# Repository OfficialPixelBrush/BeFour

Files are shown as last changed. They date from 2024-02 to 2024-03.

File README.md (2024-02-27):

# BeFour
The BeFour/B4/Be4 is a simplistic 4-Bit, TTL Processor, largely inspired by the Zilog Z80 and similar architectures of the late-1970s and early-1980s, just in 4-Bit.

# Goal
It's main idea is simple. How basic can I make an instruction set, while still making it somewhat useful?
This question arose out of need. I was originally trying to make a Diode-Transistor Logic Computer entirely from Scratch, which was meant to be 4-Bit too. However, planning that monstrocity became too difficult for my current skill-set, so I decided to try anew. My main goal not being an impressive instruction set, but something simple that won't require heaps of individual Diodes and Transistors. This is also why I'll be sticking with bog-standard TTL Chips for this project.

# Architecture
This Processor is entirely 4-Bit, aside from the Address Bus, which is 8-Bit.
This allows for Addressing of up to 256 Bytes of Memory, at least as a Program. The Processor is only capable of reading a 4-Bit address for RAM access, limiting it's Memory on that front to only 16 Bytes.

For more information about the Architecture, Instruction Set, Memory Map, et cetera, please [visit the Wiki page](https://github.com/OfficialPixelBrush/BeFour/wiki).

# Emulator
The provide Emulator is accurate enough for most simple Programs, and can be compiled easily with gcc.
Pre-built Binaries can usually be found in the Releases section, although these may not always be up-to-date.

## How to use
The emulator takes two parameters. The first is the filename of whichever Binary file it's supposed to execute. The second is how many instructions it'll execute before stopping. By default, this is -1, meaning it'll stop right away.

### Windows
To execute the provided Fibonacci Program, for example, one could use `.\b4emu.exe ..\software\fibo.bin 50` to execute the Fibbonaci Program for 50 Instructions.

### Linux
Similar to Windows, just different formatting:
`./b4emu ../software/fibo.bin 50`
Outside of that, make sure the binary is set to be executable.
`chmod +x b4emu`

## Binaries
You can find all Releases in the [Releases Section](https://github.com/OfficialPixelBrush/BeFour/releases).

# License
It's been difficult finding a proper license for this thus far, especially because I don't see why anyone'd want to do much with this thing.
It's my processor, feel free to be inspired by it, but don't steal it, and don't use it commercially. I'll probably replace this with a proper license sometime soon, but if you have any deeper questions, just shoot me a message via an Issue or something.

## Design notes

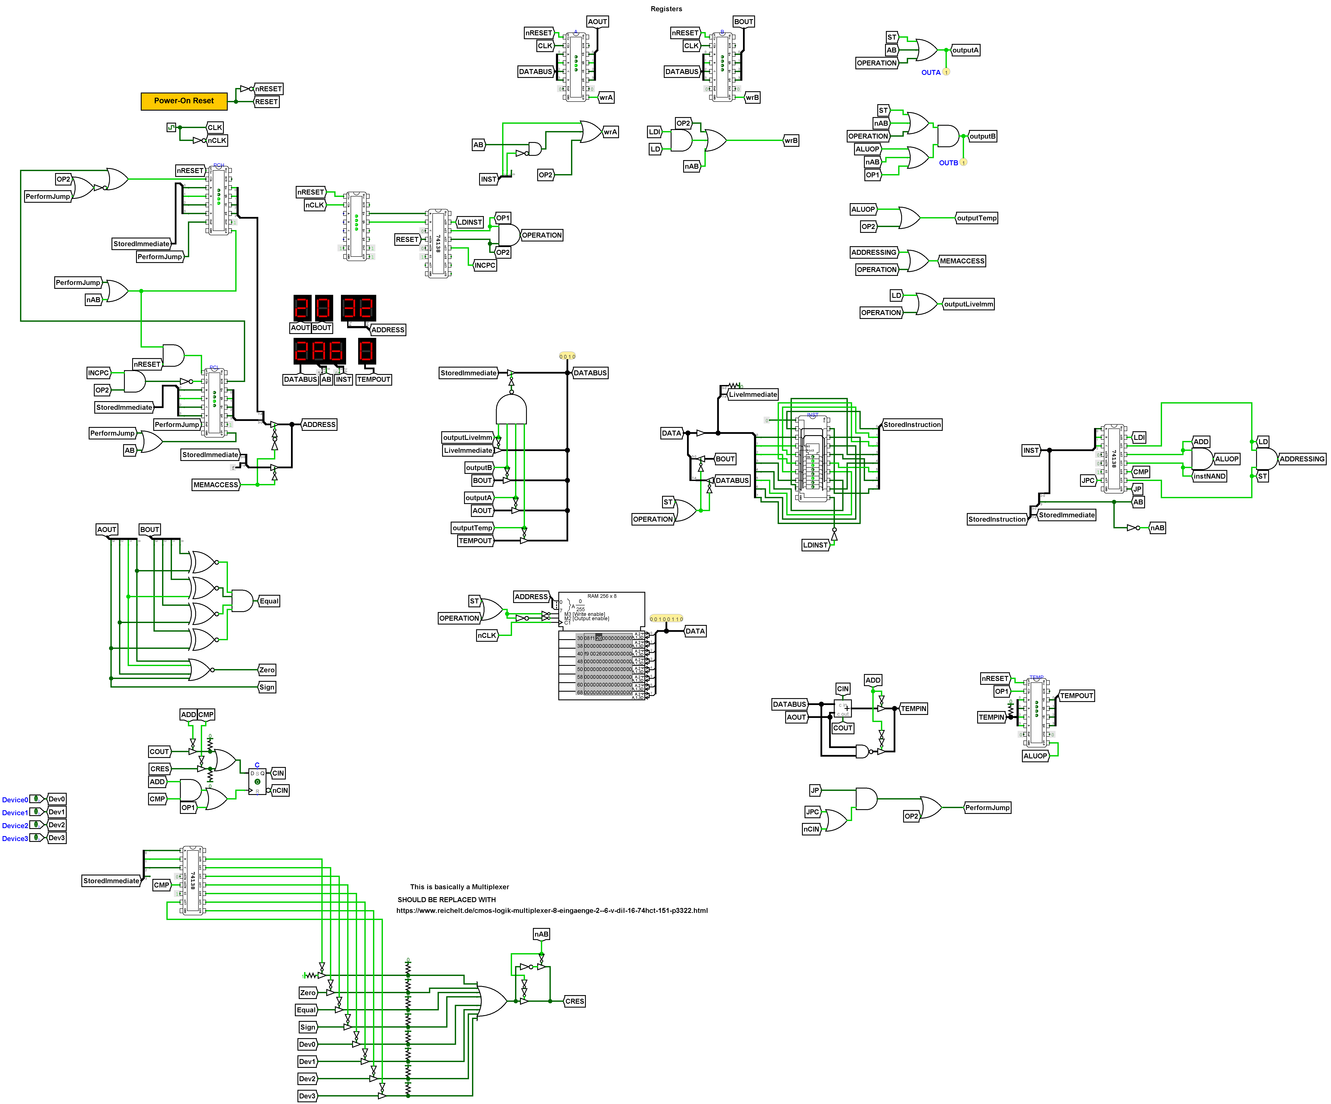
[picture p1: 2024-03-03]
images/befour_final.png

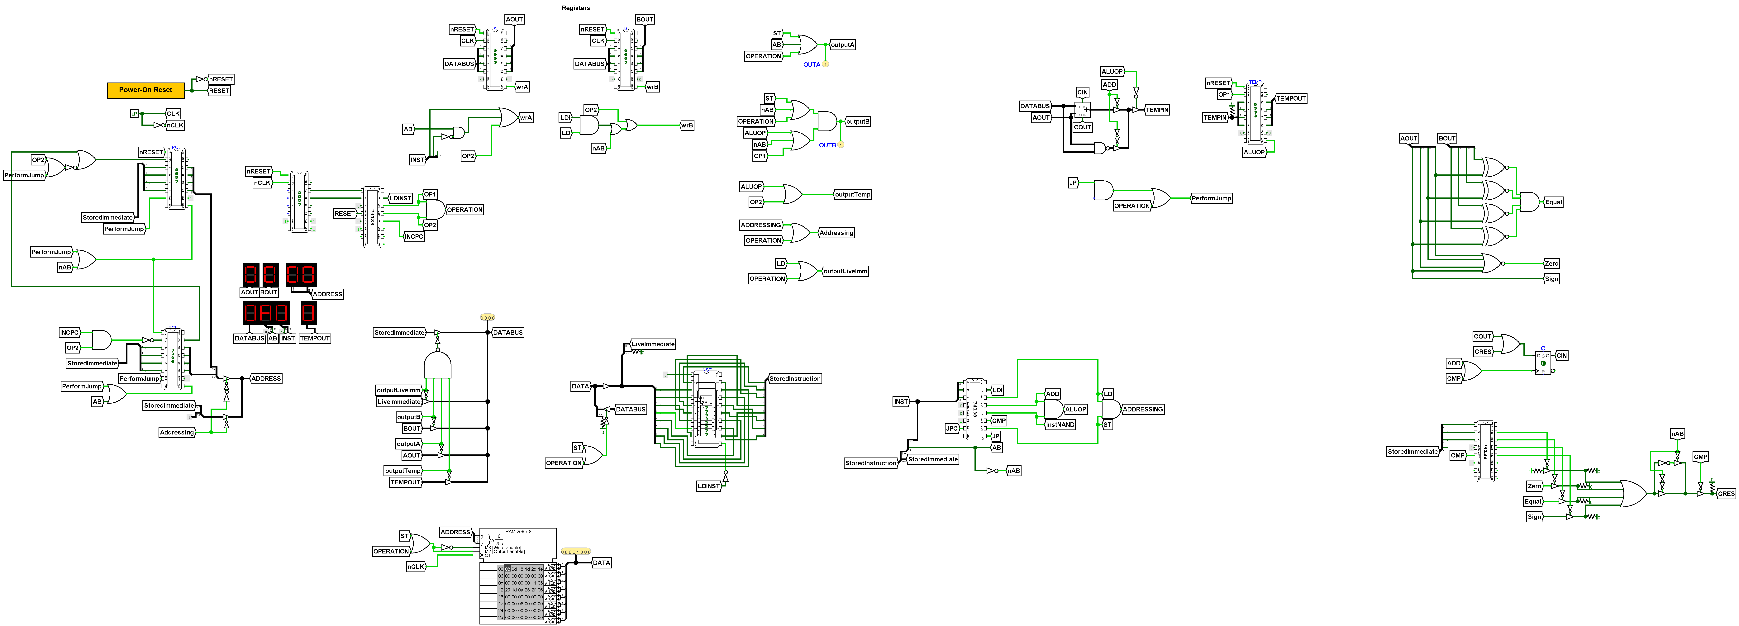
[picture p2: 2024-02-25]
images/basic4bit_cmp.png

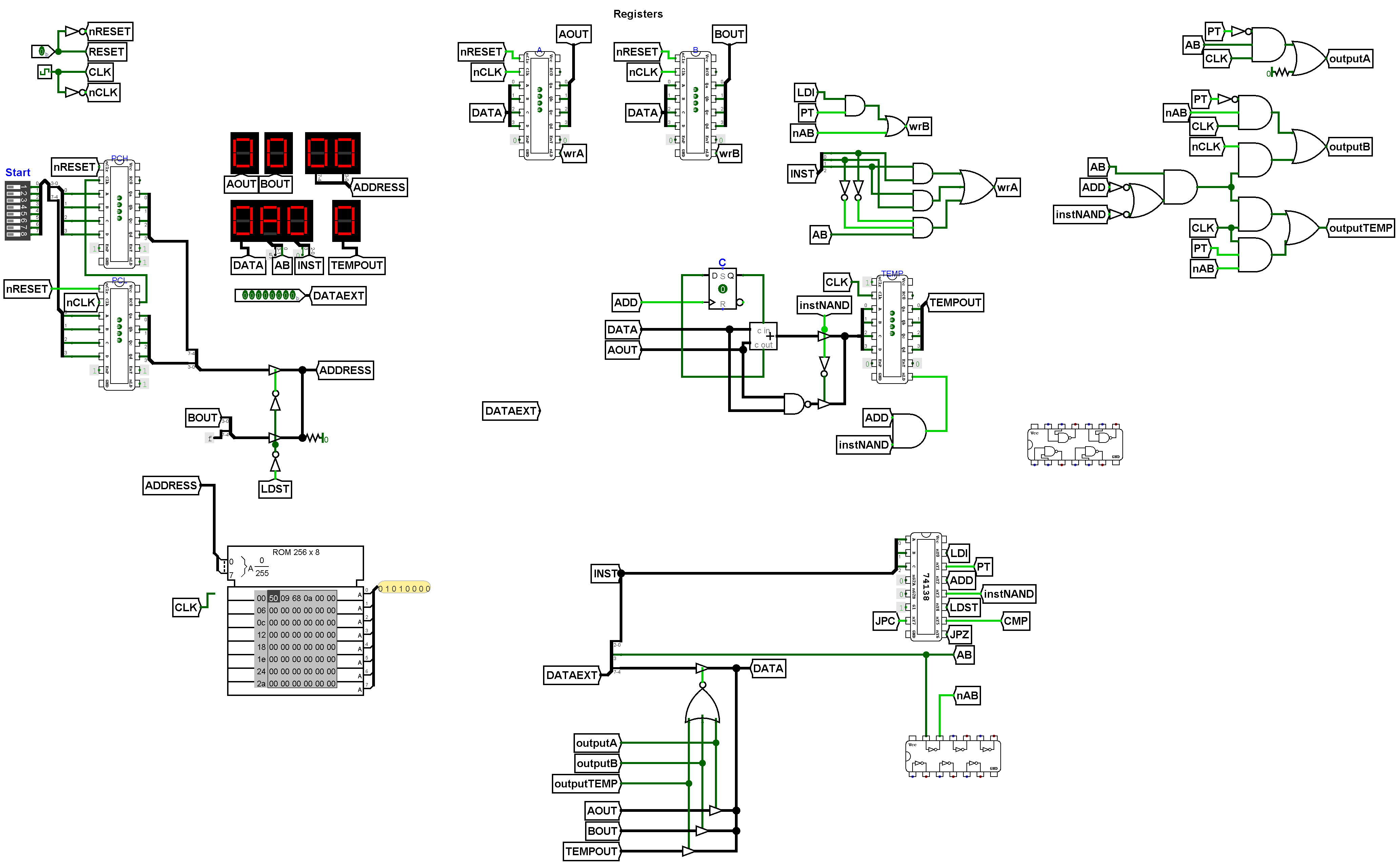
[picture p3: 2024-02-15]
images/basic4bit_halfway.png

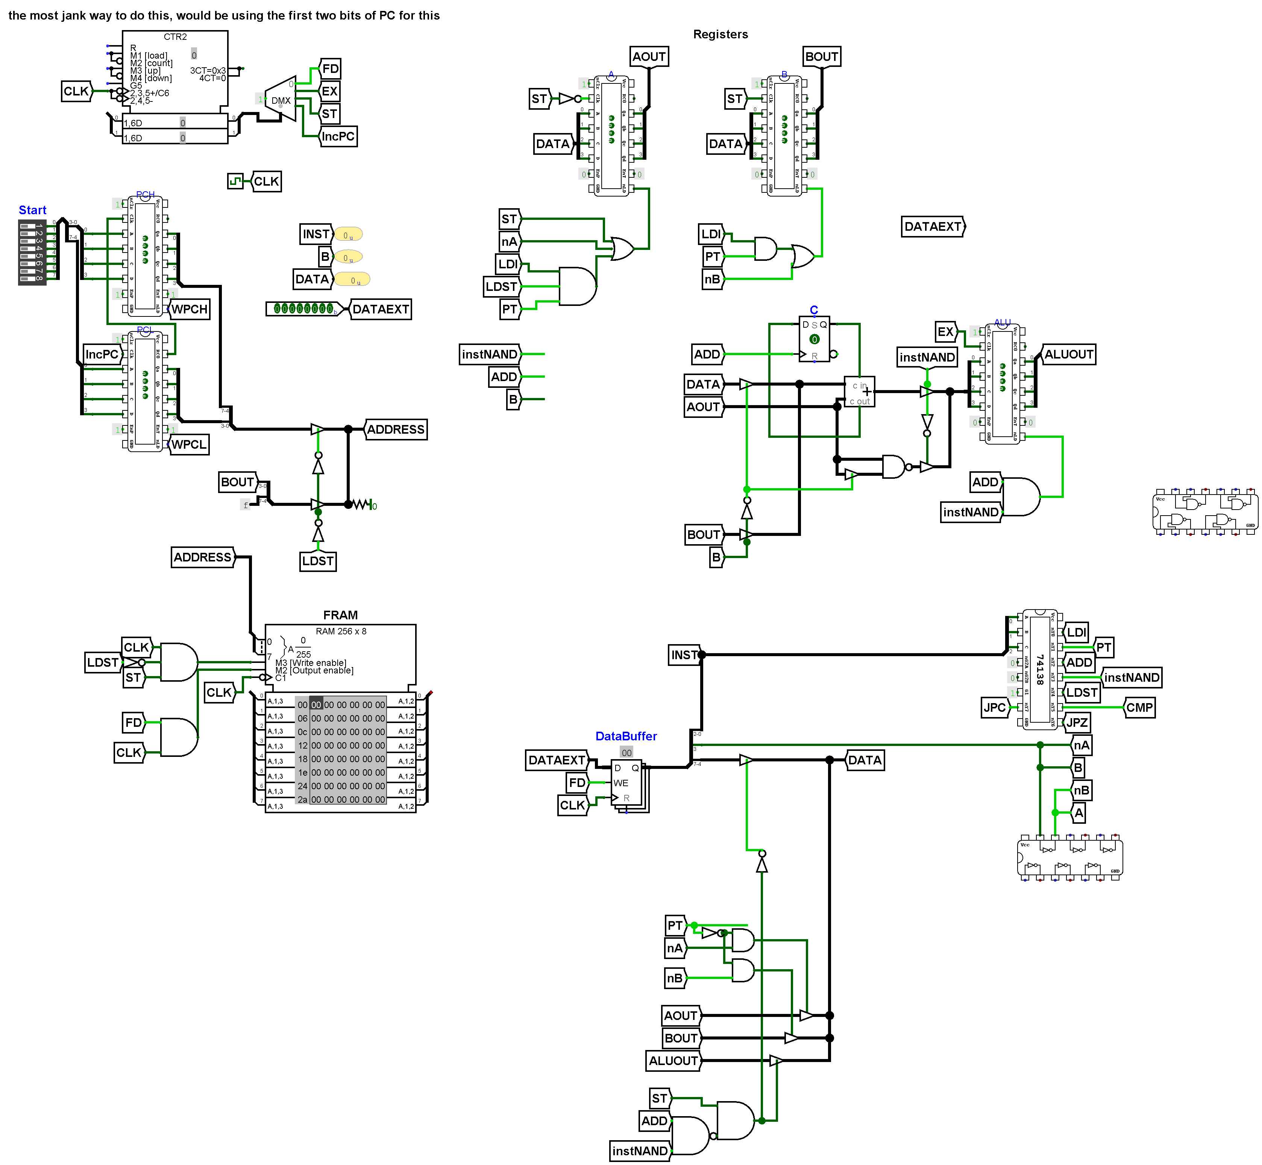
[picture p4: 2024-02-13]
images/basic4bit.png

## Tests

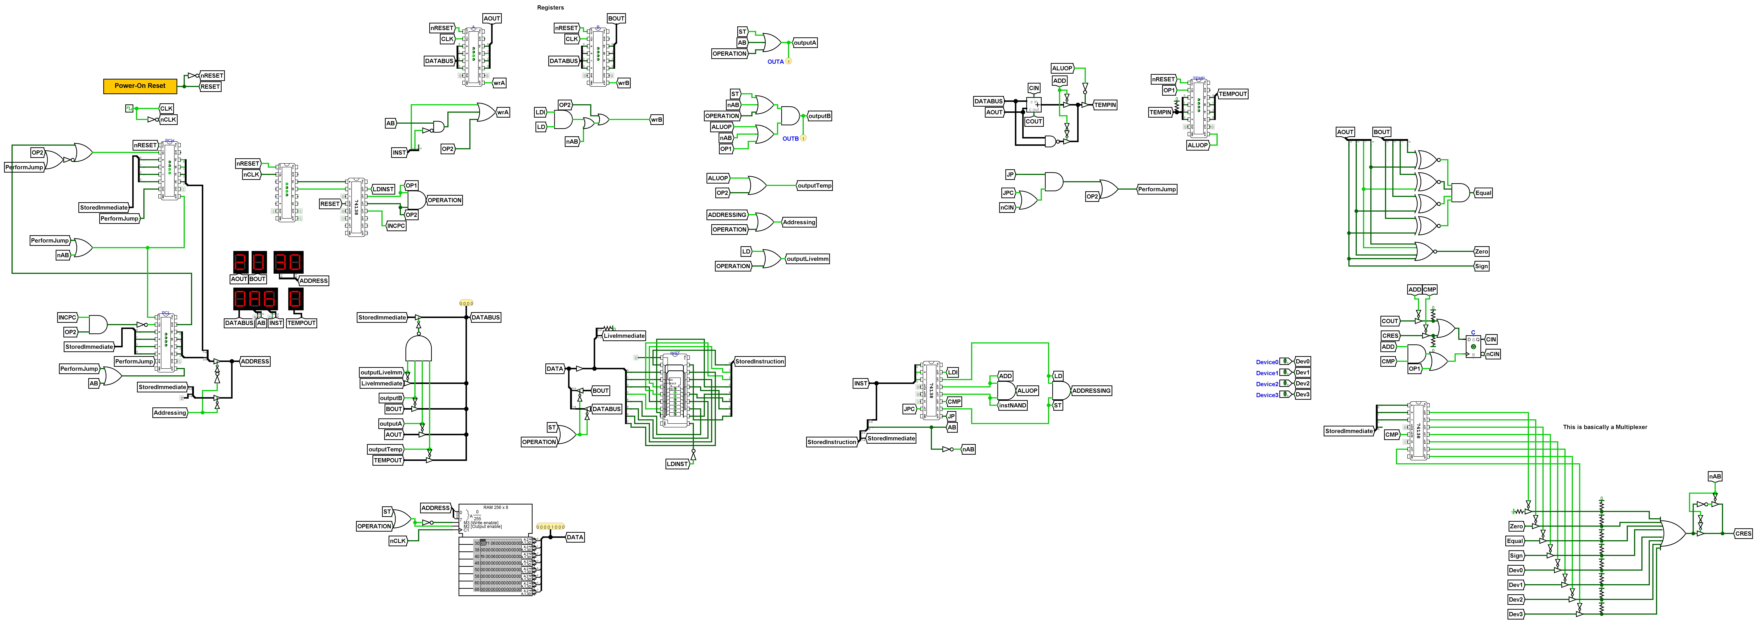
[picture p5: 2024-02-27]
images/befour_finishedTest.png

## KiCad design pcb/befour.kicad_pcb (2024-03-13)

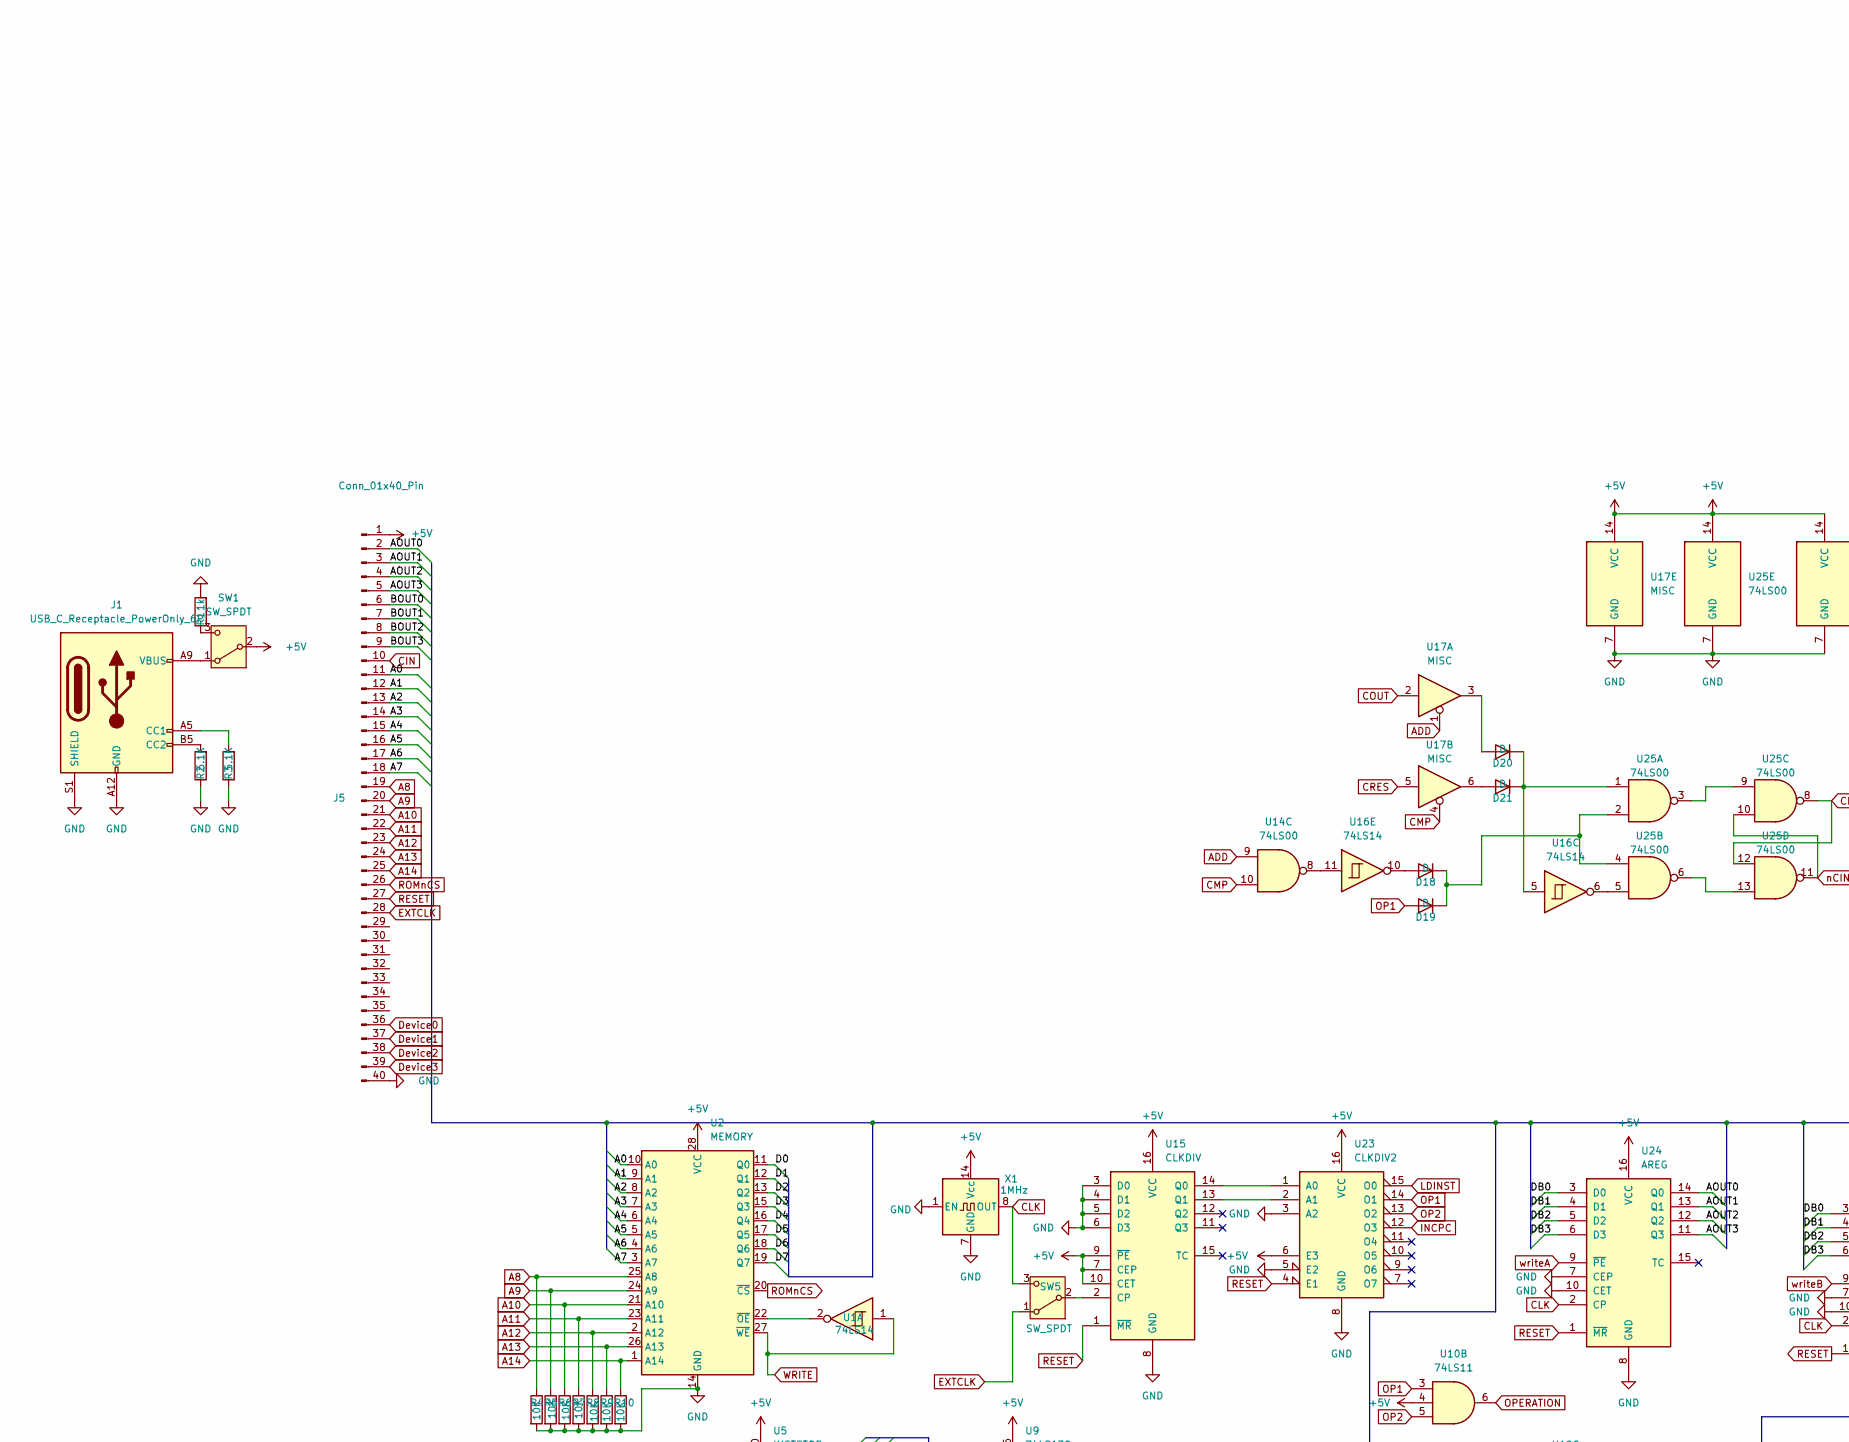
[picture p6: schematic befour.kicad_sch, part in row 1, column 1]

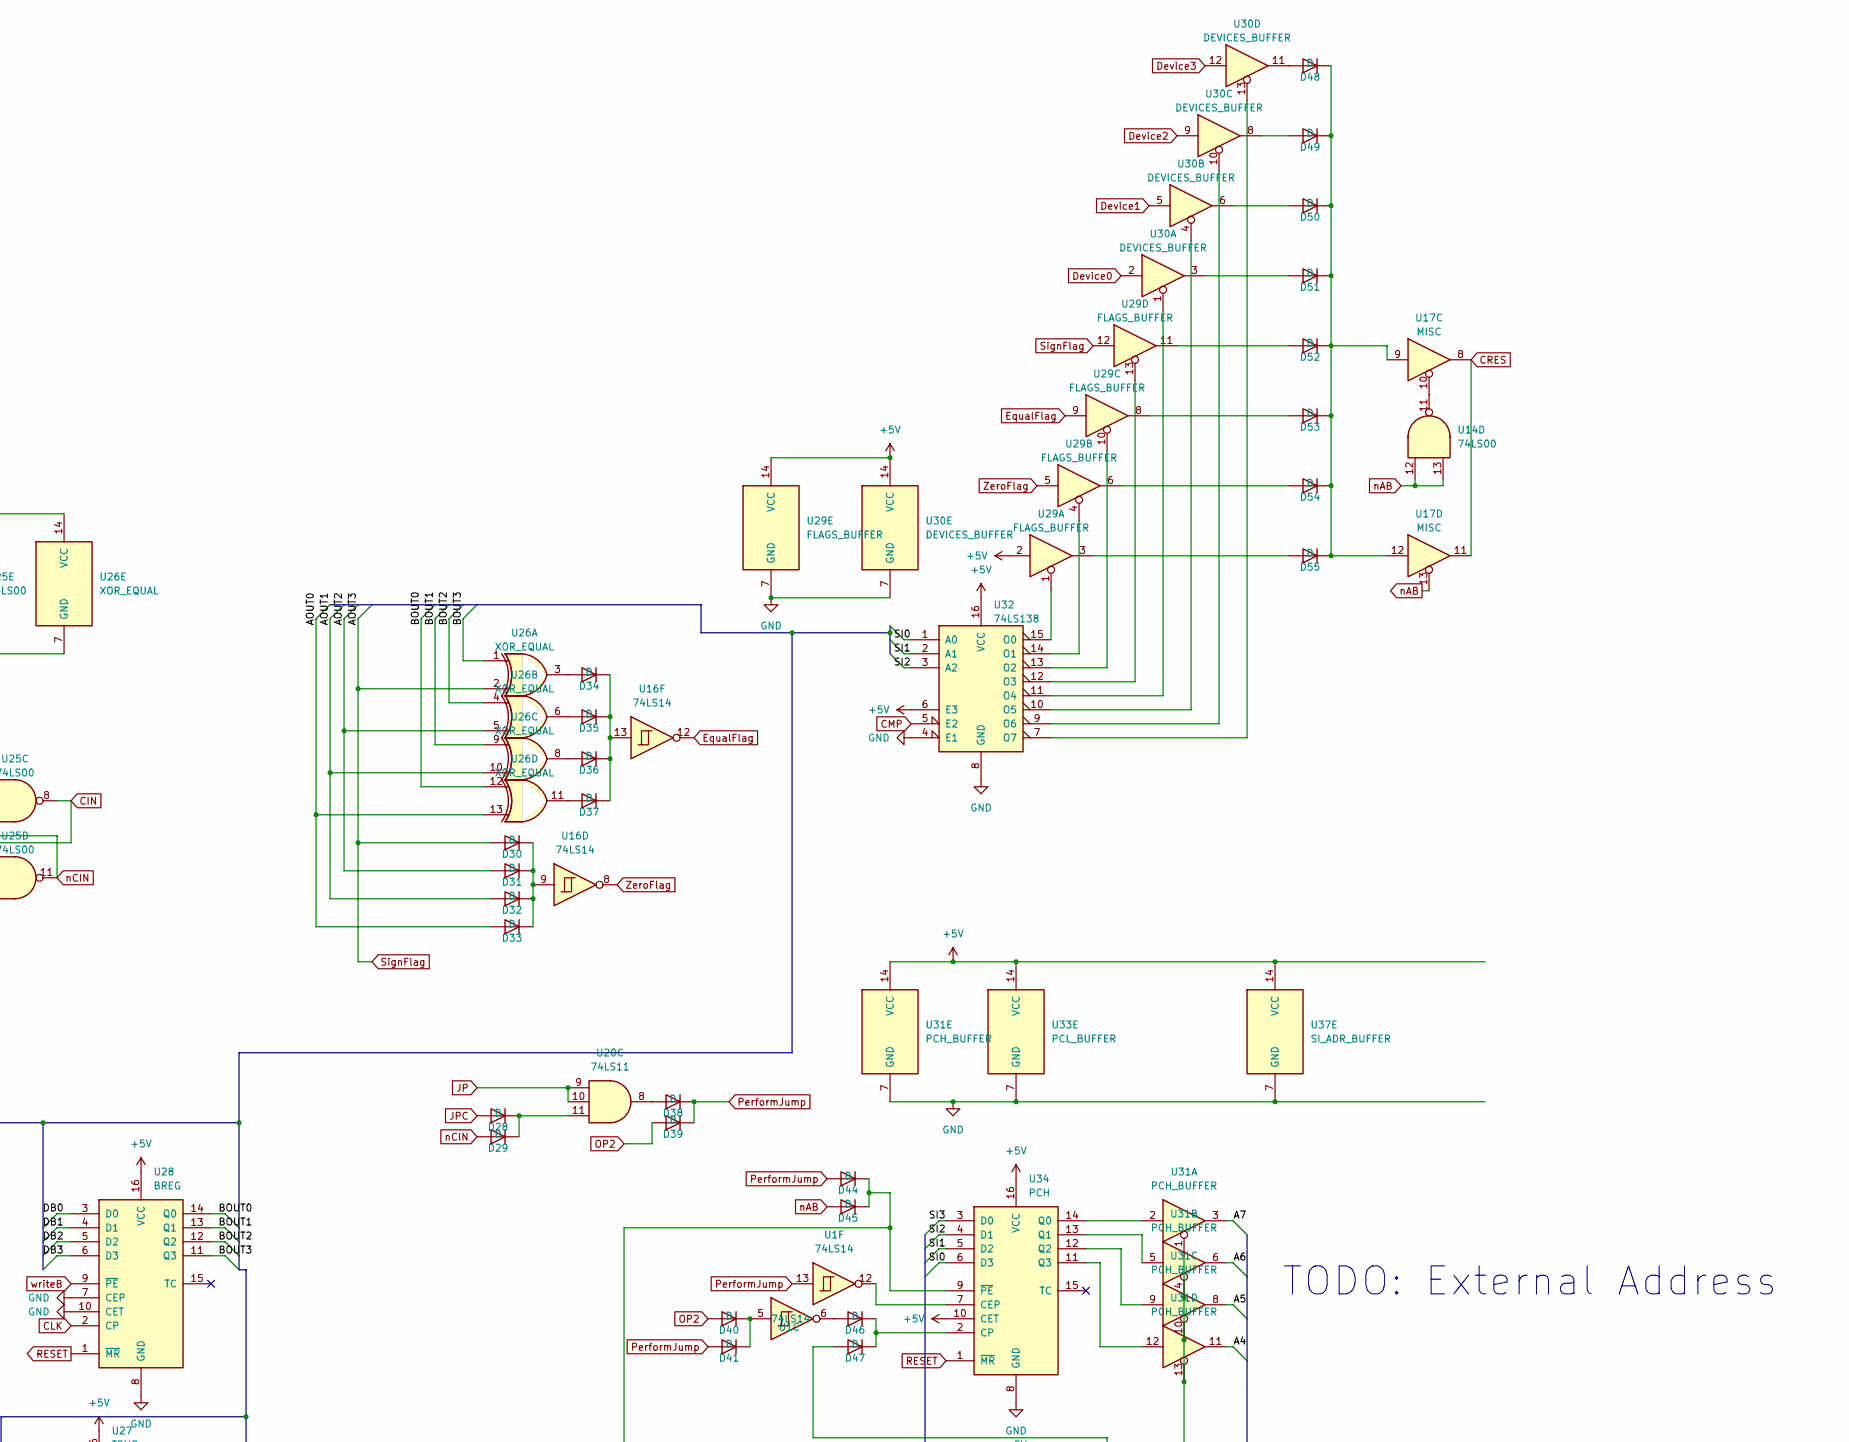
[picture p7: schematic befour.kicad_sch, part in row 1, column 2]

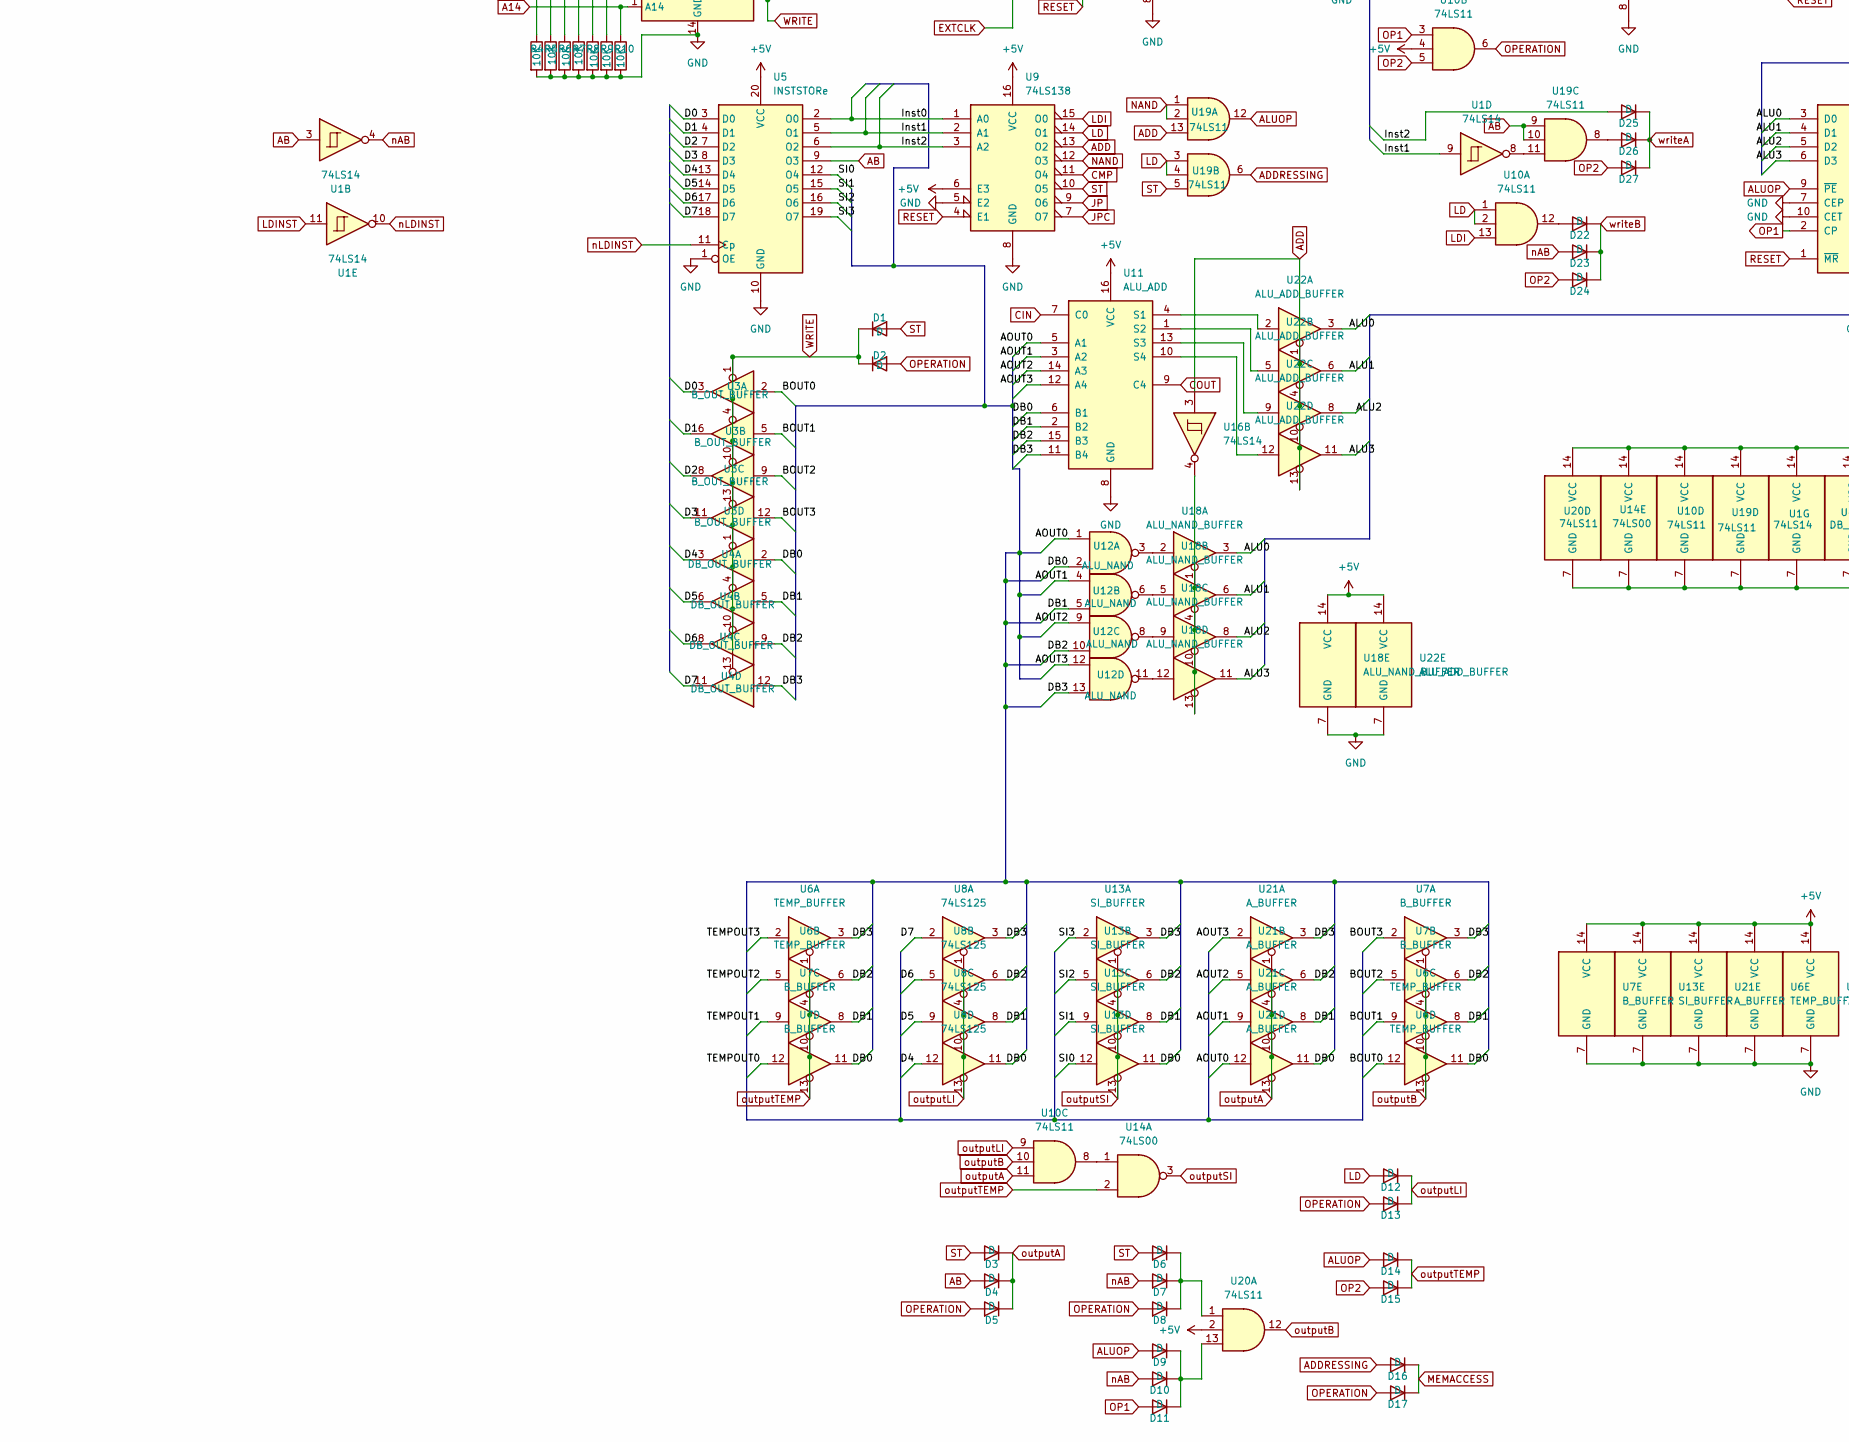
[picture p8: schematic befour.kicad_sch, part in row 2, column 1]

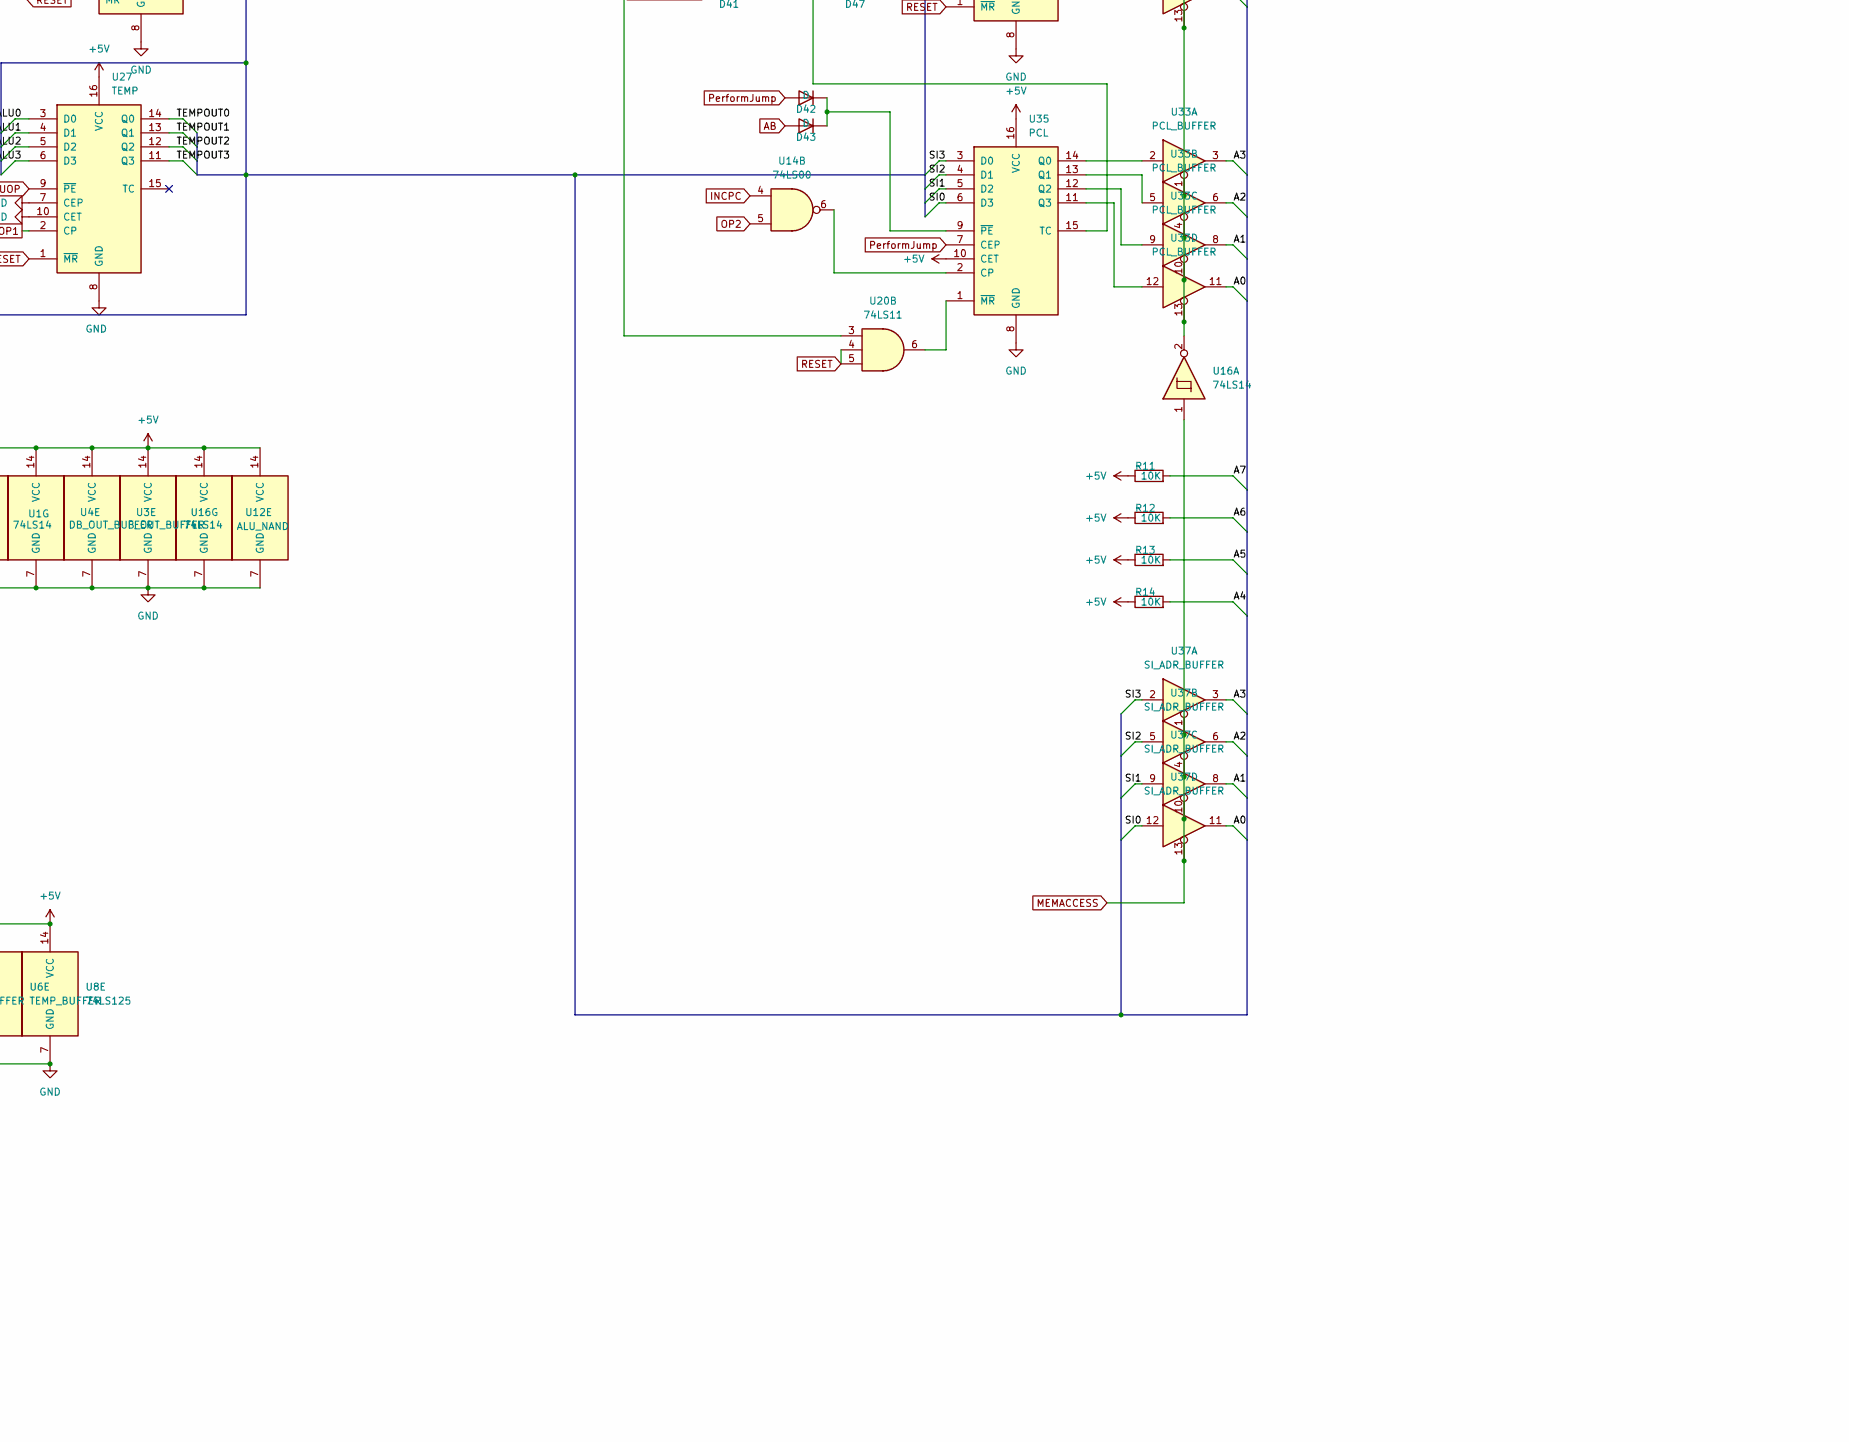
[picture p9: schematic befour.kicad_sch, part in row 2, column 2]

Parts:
D1, D2, D3, D4, D5, D6, D7, D8, D9, D10, D11, D12, D13, D14, D15, D16, D17, D18, D19, D20, D21, D22, D23, D24, D25, D26, D27, D28, D29, D30, D31, D32, D33, D34, D35, D36, D37, D38, D39, D40, D41, D42, D43, D44, D45, D46, D47, D48, D49, D50, D51, D52, D53, D54, D55: D; D_DO-35_SOD27_P2.54mm_Vertical_KathodeUp
J1: USB_C_Receptacle_PowerOnly_6P; USB_C_Receptacle_GCT_USB4125-xx-x_6P_TopMnt_Horizontal
J5: Conn_01x40_Pin; PinHeader_1x40_P2.54mm_Horizontal
R1: 1k; R_Axial_DIN0309_L9.0mm_D3.2mm_P2.54mm_Vertical
R2, R3: 5.1K; R_Axial_DIN0309_L9.0mm_D3.2mm_P2.54mm_Vertical
R4, R5, R6, R7, R8, R9, R10, R11, R12, R13, R14: 10K; R_Axial_DIN0309_L9.0mm_D3.2mm_P2.54mm_Vertical
SW1: SW_SPDT; PinHeader_1x03_P2.54mm_Vertical
SW5: SW_SPDT; SW_Slide_SPDT_Straight_CK_OS102011MS2Q
U1, U16: 74LS14; DIP-14_W7.62mm_Socket
U2: MEMORY; DIP-28_W15.24mm
U3: B_OUT_BUFFER; DIP-14_W7.62mm_Socket
U4: DB_OUT_BUFFER; DIP-14_W7.62mm_Socket
U5: INSTSTORe; DIP-20_W7.62mm_Socket
U6: TEMP_BUFFER; DIP-14_W7.62mm_Socket
U7: B_BUFFER; DIP-14_W7.62mm_Socket
U8: 74LS125; DIP-14_W7.62mm_Socket
U9, U32: 74LS138; DIP-16_W7.62mm_Socket
U10, U19, U20: 74LS11; DIP-14_W7.62mm_Socket
U11: ALU_ADD; DIP-16_W7.62mm_Socket
U12: ALU_NAND; DIP-14_W7.62mm_Socket
U13: SI_BUFFER; DIP-14_W7.62mm_Socket
U14, U25: 74LS00; DIP-14_W7.62mm_Socket
U15: CLKDIV; DIP-16_W7.62mm_Socket
U17: MISC; DIP-14_W7.62mm_Socket
U18: ALU_NAND_BUFFER; DIP-14_W7.62mm_Socket
U21: A_BUFFER; DIP-14_W7.62mm_Socket
U22: ALU_ADD_BUFFER; DIP-14_W7.62mm_Socket
U23: CLKDIV2; DIP-16_W7.62mm_Socket
U24: AREG; DIP-16_W7.62mm_Socket
U26: XOR_EQUAL; DIP-14_W7.62mm_Socket
U27: TEMP; DIP-16_W7.62mm_Socket
U28: BREG; DIP-16_W7.62mm_Socket
U29: FLAGS_BUFFER; DIP-14_W7.62mm_Socket
U30: DEVICES_BUFFER; DIP-14_W7.62mm_Socket
U31: PCH_BUFFER; DIP-14_W7.62mm_Socket
U33: PCL_BUFFER; DIP-14_W7.62mm_Socket
U34: PCH; DIP-16_W7.62mm_Socket
U35: PCL; DIP-16_W7.62mm_Socket
U37: SI_ADR_BUFFER; DIP-14_W7.62mm_Socket
X1: 1MHz; Oscillator_DIP-14

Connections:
+5V: J5.1, R11.1, R12.1, R13.1, R14.1, SW1.2 (B), U1.14 (VCC), U2.28 (VCC), U3.14 (VCC), U4.14 (VCC), U5.20 (VCC), U6.14 (VCC), U7.14 (VCC), U8.14 (VCC), U9.6 (E3), U9.16 (VCC), U10.4, U10.14 (VCC), U11.16 (VCC), U12.14 (VCC), U13.14 (VCC), U14.14 (VCC), U15.7 (CEP), U15.9 (~PE), U15.10 (CET), U15.16 (VCC), U16.14 (VCC), U17.14 (VCC), U18.14 (VCC), U19.14 (VCC), U20.2, U20.14 (VCC), U21.14 (VCC), U22.14 (VCC), U23.6 (E3), U23.16 (VCC), U24.16 (VCC), U25.14 (VCC), U26.14 (VCC), U27.16 (VCC), U28.16 (VCC), U29.2, U29.14 (VCC), U30.14 (VCC), U31.14 (VCC), U32.6 (E3), U32.16 (VCC), U33.14 (VCC), U34.10 (CET), U34.16 (VCC), U35.10 (CET), U35.16 (VCC), U37.14 (VCC), X1.14 (Vcc)
/A0: J5.11, U2.10 (A0), U33.11, U37.11
/A1: J5.12, U2.9 (A1), U33.8, U37.8
/A2: J5.13, U2.8 (A2), U33.6, U37.6
/A3: J5.14, U2.7 (A3), U33.3, U37.3
/A4: J5.15, R14.2, U2.6 (A4), U31.11
/A5: J5.16, R13.2, U2.5 (A5), U31.8
/A6: J5.17, R12.2, U2.4 (A6), U31.6
/A7: J5.18, R11.2, U2.3 (A7), U31.3
/ALU0: U18.3, U22.3, U27.3 (D0)
/ALU1: U18.6, U22.6, U27.4 (D1)
/ALU2: U18.8, U22.8, U27.5 (D2)
/ALU3: U18.11, U22.11, U27.6 (D3)
/AOUT0: D33.2 (A), J5.2, U11.5 (A1), U12.1, U21.12, U24.14 (Q0), U26.13
/AOUT1: D32.2 (A), J5.3, U11.3 (A2), U12.4, U21.9, U24.13 (Q1), U26.10
/AOUT2: D31.2 (A), J5.4, U11.14 (A3), U12.9, U21.5, U24.12 (Q2), U26.5
/BOUT0: J5.6, U3.2, U6.12, U26.12, U28.14 (Q0)
/BOUT1: J5.7, U3.5, U6.9, U26.9, U28.13 (Q1)
/BOUT2: J5.8, U3.9, U7.5, U26.4, U28.12 (Q2)
/BOUT3: J5.9, U3.12, U7.2, U26.1, U28.11 (Q3)
/D0: U2.11 (Q0), U3.3, U5.3 (D0)
/D1: U2.12 (Q1), U3.6, U5.4 (D1)
/D2: U2.13 (Q2), U3.8, U5.7 (D2)
/D3: U2.15 (Q3), U3.11, U5.8 (D3)
/D4: U2.16 (Q4), U4.3, U5.13 (D4), U8.12
/D5: U2.17 (Q5), U4.6, U5.14 (D5), U8.9
/D6: U2.18 (Q6), U4.8, U5.17 (D6), U8.5
/D7: U2.19 (Q7), U4.11, U5.18 (D7), U8.2
/DB0: U4.2, U6.11, U7.11, U8.11, U11.6 (B1), U12.2, U13.11, U21.11, U24.3 (D0), U28.3 (D0)
/DB1: U4.5, U6.8, U7.8, U8.8, U11.2 (B2), U12.5, U13.8, U21.8, U24.4 (D1), U28.4 (D1)
/DB2: U4.9, U6.6, U7.6, U8.6, U11.15 (B3), U12.10, U13.6, U21.6, U24.5 (D2), U28.5 (D2)
/DB3: U4.12, U6.3, U7.3, U8.3, U11.11 (B4), U12.13, U13.3, U21.3, U24.6 (D3), U28.6 (D3)
/Inst0: U5.2 (O0), U9.1 (A0)
/Inst1: U1.9, U5.5 (O1), U9.2 (A1)
/Inst2: D25.2 (A), U5.6 (O2), U9.3 (A2)
/SI0: U5.12 (O4), U13.12, U32.1 (A0), U34.6 (D3), U35.6 (D3), U37.12
/SI1: U5.15 (O5), U13.9, U32.2 (A1), U34.5 (D2), U35.5 (D2), U37.9
/SI2: U5.16 (O6), U13.5, U32.3 (A2), U34.4 (D1), U35.4 (D1), U37.5
/SI3: U5.19 (O7), U13.2, U34.3 (D0), U35.3 (D0), U37.2
/TEMPOUT0: U7.12, U27.14 (Q0)
/TEMPOUT1: U7.9, U27.13 (Q1)
/TEMPOUT2: U6.5, U27.12 (Q2)
/TEMPOUT3: U6.2, U27.11 (Q3)
A8: J5.19, R4.1, U2.25 (A8)
A9: J5.20, R5.1, U2.24 (A9)
A10: J5.21, R6.1, U2.21 (A10)
A11: J5.22, R7.1, U2.23 (A11)
A12: J5.23, R8.1, U2.2 (A12)
A13: J5.24, R9.1, U2.26 (A13)
A14: J5.25, R10.1, U2.1 (A14)
AB: D4.2 (A), D43.2 (A), U1.3, U5.9 (O3), U19.9, U19.10
ADD: U9.13 (O2), U14.9, U16.3, U17.1, U19.13, U22.1, U22.4, U22.10, U22.13
ADDRESSING: D16.2 (A), U19.6
ALUOP: D9.2 (A), D14.2 (A), U19.12, U27.9 (~PE)
CIN: J5.10, U11.7 (C0), U25.8, U25.12
CLK: SW5.3 (C), U24.2 (CP), U28.2 (CP), X1.8 (OUT)
CMP: U9.11 (O4), U14.10, U17.4, U32.5 (E2)
COUT: U11.9 (C4), U17.2
CRES: U17.5, U17.8, U17.11
Device0: J5.36, U30.2
Device1: J5.37, U30.5
Device2: J5.38, U30.9
Device3: J5.39, U30.12
EXTCLK: J5.28, SW5.1 (A)
EqualFlag: U16.12, U29.9
GND: J1.A12 (GND), J1.B12 (GND), J1.S1 (SHIELD), J5.40, R1.2, R2.1, R3.1, R4.2, R5.2, R6.2, R7.2, R8.2, R9.2, R10.2, U1.7 (GND), U2.14 (GND), U3.7 (GND), U4.7 (GND), U5.1 (OE), U5.10 (GND), U6.7 (GND), U7.7 (GND), U8.7 (GND), U9.5 (E2), U9.8 (GND), U10.7 (GND), U11.8 (GND), U12.7 (GND), U13.7 (GND), U14.7 (GND), U15.3 (D0), U15.4 (D1), U15.5 (D2), U15.6 (D3), U15.8 (GND), U16.7 (GND), U17.7 (GND), U18.7 (GND), U19.7 (GND), U20.7 (GND), U21.7 (GND), U22.7 (GND), U23.3 (A2), U23.5 (E2), U23.8 (GND), U24.7 (CEP), U24.8 (GND), U24.10 (CET), U25.7 (GND), U26.7 (GND), U27.7 (CEP), U27.8 (GND), U27.10 (CET), U28.7 (CEP), U28.8 (GND), U28.10 (CET), U29.7 (GND), U30.7 (GND), U31.7 (GND), U32.4 (E1), U32.8 (GND), U33.7 (GND), U34.8 (GND), U35.8 (GND), U37.7 (GND), X1.1 (EN), X1.7 (GND)
INCPC: U14.4, U23.12 (O3)
JP: U9.9 (O6), U20.9, U20.10
JPC: D28.2 (A), U9.7 (O7)
LD: D12.2 (A), U9.14 (O1), U10.1, U10.2, U19.3, U19.4
LDI: U9.15 (O0), U10.13
LDINST: U1.11, U23.15 (O0)
MEMACCESS: D16.1 (K), D17.1 (K), U16.1, U37.1, U37.4, U37.10, U37.13
NAND: U9.12 (O3), U19.1, U19.2
unnamed: D6.1 (K), D7.1 (K), D8.1 (K), U20.1
unnamed: D9.1 (K), D10.1 (K), D11.1 (K), U20.13
unnamed: D18.2 (A), U16.10
unnamed: D18.1 (K), D19.1 (K), U25.2, U25.4
unnamed: D20.2 (A), U17.3
unnamed: D20.1 (K), D21.1 (K), U16.5, U25.1
unnamed: D21.2 (A), U17.6
unnamed: D22.2 (A), U10.12
unnamed: D26.2 (A), U19.8
unnamed: D28.1 (K), D29.1 (K), U20.11
unnamed: D30.1 (K), D31.1 (K), D32.1 (K), D33.1 (K), U16.9
unnamed: D34.2 (A), U26.3
unnamed: D34.1 (K), D35.1 (K), D36.1 (K), D37.1 (K), U16.13
unnamed: D35.2 (A), U26.6
unnamed: D36.2 (A), U26.8
unnamed: D37.2 (A), U26.11
unnamed: D38.2 (A), U20.8
unnamed: D40.1 (K), D41.1 (K), U1.5
unnamed: D42.1 (K), D43.1 (K), U35.9 (~PE)
unnamed: D44.1 (K), D45.1 (K), U20.3, U34.9 (~PE)
unnamed: D46.2 (A), U1.6
unnamed: D46.1 (K), D47.1 (K), U34.2 (CP)
unnamed: D47.2 (A), U35.15 (TC)
unnamed: D48.2 (A), U30.11
unnamed: D48.1 (K), D49.1 (K), D50.1 (K), D51.1 (K), D52.1 (K), D53.1 (K), D54.1 (K), D55.1 (K), U17.9, U17.12
unnamed: D49.2 (A), U30.8
unnamed: D50.2 (A), U30.6
unnamed: D51.2 (A), U30.3
unnamed: D52.2 (A), U29.11
unnamed: D53.2 (A), U29.8
unnamed: D54.2 (A), U29.6
unnamed: D55.2 (A), U29.3
unnamed: J1.A5 (CC1), R3.2
unnamed: J1.B5 (CC2), R2.2
unnamed: J1.A9 (VBUS), J1.B9 (VBUS), SW1.1 (A)
unnamed: R1.1, SW1.3 (C)
unnamed: SW5.2 (B), U15.2 (CP)
unnamed: U1.8, U19.11
unnamed: U1.2, U2.22 (~OE)
unnamed: U10.8, U14.1
unnamed: U11.4 (S1), U22.2
unnamed: U11.1 (S2), U22.5
unnamed: U11.13 (S3), U22.9
unnamed: U11.10 (S4), U22.12
unnamed: U12.3, U18.2
unnamed: U12.6, U18.5
unnamed: U12.8, U18.9
unnamed: U12.11, U18.12
unnamed: U14.8, U16.11
unnamed: U14.11, U17.10
unnamed: U15.14 (Q0), U23.1 (A0)
unnamed: U15.13 (Q1), U23.2 (A1)
unnamed: U16.2, U31.1, U31.4, U31.10, U31.13, U33.1, U33.4, U33.10, U33.13
unnamed: U16.4, U18.1, U18.4, U18.10, U18.13
unnamed: U16.6, U25.5
unnamed: U25.3, U25.9
unnamed: U25.6, U25.13
unnamed: U29.1, U32.15 (O0)
unnamed: U29.4, U32.14 (O1)
unnamed: U29.10, U32.13 (O2)
unnamed: U29.13, U32.12 (O3)
unnamed: U30.1, U32.11 (O4)
unnamed: U30.4, U32.10 (O5)
unnamed: U30.10, U32.9 (O6)
unnamed: U30.13, U32.7 (O7)
unnamed: U1.12, U34.7 (CEP)
unnamed: U31.2, U34.14 (Q0)
unnamed: U31.5, U34.13 (Q1)
unnamed: U31.9, U34.12 (Q2)
unnamed: U31.12, U34.11 (Q3)
unnamed: U14.6, U35.2 (CP)
unnamed: U33.2, U35.14 (Q0)
unnamed: U33.5, U35.13 (Q1)
unnamed: U33.9, U35.12 (Q2)
unnamed: U33.12, U35.11 (Q3)
unnamed: U20.6, U35.1 (~MR)
OP1: D11.2 (A), D19.2 (A), U10.3, U23.14 (O1), U27.2 (CP)
OP2: D15.2 (A), D24.2 (A), D27.2 (A), D39.2 (A), D40.2 (A), U10.5, U14.5, U23.13 (O2)
OPERATION: D2.2 (A), D5.2 (A), D8.2 (A), D13.2 (A), D17.2 (A), U10.6
PerformJump: D38.1 (K), D39.1 (K), D41.2 (A), D42.2 (A), D44.2 (A), U1.13, U35.7 (CEP)
RESET: J5.27, U9.4 (E1), U15.1 (~MR), U20.4, U20.5, U23.4 (E1), U24.1 (~MR), U27.1 (~MR), U28.1 (~MR), U34.1 (~MR)
ROMnCS: J5.26, U2.20 (~CS)
ST: D1.2 (A), D3.2 (A), D6.2 (A), U9.10 (O5), U19.5
SignFlag: D30.2 (A), J5.5, U11.12 (A4), U12.12, U21.2, U24.11 (Q3), U26.2, U29.12
WRITE: D1.1 (K), D2.1 (K), U1.1, U2.27 (~WE), U3.1, U3.4, U3.10, U3.13, U4.1, U4.4, U4.10, U4.13
ZeroFlag: U16.8, U29.5
nAB: D7.2 (A), D10.2 (A), D23.2 (A), D45.2 (A), U1.4, U14.12, U14.13, U17.13
nCIN: D29.2 (A), U25.10, U25.11
nLDINST: U1.10, U5.11 (Cp)
outputA: D3.1 (K), D4.1 (K), D5.1 (K), U10.11, U21.1, U21.4, U21.10, U21.13
outputB: U6.10, U6.13, U7.1, U7.4, U10.10, U20.12
outputLI: D12.1 (K), D13.1 (K), U8.1, U8.4, U8.10, U8.13, U10.9
outputSI: U13.1, U13.4, U13.10, U13.13, U14.3
outputTEMP: D14.1 (K), D15.1 (K), U6.1, U6.4, U7.10, U7.13, U14.2
writeA: D25.1 (K), D26.1 (K), D27.1 (K), U24.9 (~PE)
writeB: D22.1 (K), D23.1 (K), D24.1 (K), U28.9 (~PE)

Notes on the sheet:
TODO: External Address

Board: 2 copper layers, 110 parts (0 on the bottom side), 170 nets, no tracks yet.

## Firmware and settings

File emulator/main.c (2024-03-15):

#include <stdio.h>
#include <stdlib.h>

#define MEMSIZE 256
typedef unsigned char byte;
typedef unsigned short word;

#define printCurrentState 1 << 0
#define printExecInst     1 << 1
#define printChanges 	  1 << 2

byte INTMEM[MEMSIZE] = {
	0x30, 0x58, 0x01, 0x30, 0xf9, 0x72, 0xfa, 0x04, 0x00, 0x00, 0x00, 0x00, 0x00, 0x00, 0x00, 0x00, 
	0x00, 0x00, 0x00, 0x00, 0x00, 0x00, 0x00, 0x00, 0x00, 0x00, 0x00, 0x00, 0x00, 0x00, 0x00, 0x00, 
	0x00, 0x00, 0x00, 0x00, 0x00, 0x00, 0x00, 0x00, 0x00, 0x00, 0x00, 0x00, 0x00, 0x00, 0x00, 0x00, 
	0x00, 0x00, 0x00, 0x00, 0x00, 0x00, 0x00, 0x00, 0x00, 0x00, 0x00, 0x00, 0x00, 0x00, 0x00, 0x00, 
	0x00, 0x00, 0x00, 0x00, 0x00, 0x00, 0x00, 0x00, 0x00, 0x00, 0x00, 0x00, 0x00, 0x00, 0x00, 0x00, 
	0x00, 0x00, 0x00, 0x00, 0x00, 0x00, 0x00, 0x00, 0x00, 0x00, 0x00, 0x00, 0x00, 0x00, 0x00, 0x00, 
	0x00, 0x00, 0x00, 0x00, 0x00, 0x00, 0x00, 0x00, 0x00, 0x00, 0x00, 0x00, 0x00, 0x00, 0x00, 0x00, 
	0x00, 0x00, 0x00, 0x00, 0x00, 0x00, 0x00, 0x00, 0x00, 0x00, 0x00, 0x00, 0x00, 0x00, 0x00, 0x00, 
	0x00, 0x00, 0x00, 0x00, 0x00, 0x00, 0x00, 0x00, 0x00, 0x00, 0x00, 0x00, 0x00, 0x00, 0x00, 0x00, 
	0x00, 0x00, 0x00, 0x00, 0x00, 0x00, 0x00, 0x00, 0x00, 0x00, 0x00, 0x00, 0x00, 0x00, 0x00, 0x00, 
	0x00, 0x00, 0x00, 0x00, 0x00, 0x00, 0x00, 0x00, 0x00, 0x00, 0x00, 0x00, 0x00, 0x00, 0x00, 0x00, 
	0x00, 0x00, 0x00, 0x00, 0x00, 0x00, 0x00, 0x00, 0x00, 0x00, 0x00, 0x00, 0x00, 0x00, 0x00, 0x00, 
	0x00, 0x00, 0x00, 0x00, 0x00, 0x00, 0x00, 0x00, 0x00, 0x00, 0x00, 0x00, 0x00, 0x00, 0x00, 0x00, 
	0x00, 0x00, 0x00, 0x00, 0x00, 0x00, 0x00, 0x00, 0x00, 0x00, 0x00, 0x00, 0x00, 0x00, 0x00, 0x00, 
	0x00, 0x00, 0x00, 0x00, 0x00, 0x00, 0x00, 0x00, 0x00, 0x00, 0x00, 0x00, 0x00, 0x00, 0x00, 0x00, 
	0x99, 0xaa, 0xbb, 0xcc, 0xdd, 0xee, 0xff, 0xf1, 0x11, 0x22, 0x33, 0x44, 0x55, 0x66, 0x77, 0x88
};

// Internal Vars
byte mem[MEMSIZE];
int maxCycle = -1;
int currentCycle = 0;
int debugOutput = 0;

// Regs
byte A = 0;
byte B = 0;
word PC = 0;
byte conditionalFlag = 0;

// Old Regs
byte oldA = 0;
byte oldB = 0;
word oldPC = 0;
byte oldConditionalFlag = 0;

// Internal magics
byte inst, immediate = 0x0;
byte jumped = 0;

int printIndent() {
	if (debugOutput & ~printChanges) {
		printf("\t\t");
	}
}

int printExecutedInstruction() {
	printf("%02X: ", PC);
	switch(inst) {
		// A mode
		case 0x0: // LDI
			printf("LDI %01X,A", immediate);
			break;
		case 0x1: // LD
			printf("LD [%01X],A (%01X)", immediate, A);
			break;
		case 0x2: // ADD
			printf("ADD %01X,A (%d+%d+%d)", immediate, oldA, immediate, oldConditionalFlag);
			break;
		case 0x3: // NAND
			printf("NAND %01X,A (%d nand %d)", immediate, oldA, immediate);
			break;
		case 0x4: // CMP
			printf("CMP ");
			switch(immediate & 0b0111) {
				case 0: // Set
					printf("Set");
					break;
				case 1: // Zero
					printf("Zero");
					break;
				case 2: // Equal
					printf("Equal");
					break;
				case 3: // Sign
					printf("Sign");
					break;
				default:
					printf("Invalid condition!\n");
			}
			break;
		case 0x5: // ST
			printf("ST A,[%01X] (%01X%01X)", immediate, A&0xF, B);
			break;
		case 0x6: // STPC
			printf("SP PCL,[%03X]", PC);
			break;
		case 0x7: // JP
			printf("JP");
			break;
		// B mode
		case 0x8: // LDI
			printf("LDI %01X,B", immediate);
			break;
		case 0x9: // LD
			printf("LD [%01X],B (%01X)", immediate, B);
			break;
		case 0xA: // ADD
			printf("ADD B,A (%d+%d+%d)", oldA, oldB, oldConditionalFlag);
			break;
		case 0xB: // NAND
			printf("NAND B,A (%d nand %d)", oldA, oldB);
			break;
		case 0xC: // CMP
			printf("CMP ");
			switch(immediate & 0b0111) {
				case 0: // Reset
					printf("Reset");
					break;
				case 1: // Not Zero
					printf("Not Zero");
					break;
				case 2: // Not Equal
					printf("Not Equal");
					break;
				case 3: // Not Sign
					printf("Not Sign");
					break;
				default:
					printf("Invalid condition!\n");
			}
			break;
		case 0xD: // ST
			printf("ST B,[%01X] (%01X%01X)", immediate, B,B);
			break;
		case 0xE: // JP
			printf("JP (far)");
			break;
		case 0xF: // JPC
			printf("JPC (far)");
			break;
	}
	printf("\n");
	return 0;
}

int main(int argc, char *argv[]) {
	FILE *fptr;
	
	// Argument Handling
	if (argc > 1) {
		// Get the file
		if ((fptr = fopen(argv[1],"rb")) == NULL){
			printf("Error! opening file");

			// Program exits if the file pointer returns NULL.
			return 1;
		}
		//while()
		fread(&mem, sizeof(byte), MEMSIZE, fptr); 
		fclose(fptr);

		if (argc > 2) {
			// Stop after # of cycles
			debugOutput = atoi(argv[2]);
		}

		if (argc > 3) {
			// Stop after # of cycles
			maxCycle = atoi(argv[3]);
		}
	} else {
		for (int i = 0; i < MEMSIZE; i++) {
			mem[i] = INTMEM[i];
		}
	}
	
	while((currentCycle < maxCycle) || (maxCycle == -1)) {
		inst = mem[PC] & 0x0F;
		immediate = (mem[PC] & 0xF0) >> 4;

		//printf("A:%X, B: %X | PC:%02X\n",A,B,PC);
		if (debugOutput & printCurrentState) {
			printf("Inst: %X, immediate: %X | A:%X, B: %X, Cond:%X | PC:%02X\n", inst,immediate,A,B,conditionalFlag,PC);
		}

		// For multi-byte instructions
		switch(inst & 0b0111) {
			case 0x1: // LD
			case 0x5: // ST
			case 0x6: // STPC
			case 0x7: // JP/JPC
				PC++;
				PC &= 0xFFF;
				immediate = immediate | (mem[PC] << 4);
				printf("Multi-byte:\t");
				break;
		}

		switch(inst) {
			// A mode
			case 0x0: // LDI
				A = immediate;
				break;
			case 0x1: // LD
				A = mem[0xF0 | immediate] >> 4;
				break;
			case 0x2: // ADD
				A = A + immediate + conditionalFlag;
				if (A > 0xF) {
					A = A & 0xF;
					conditionalFlag = 1;
				} else {
					conditionalFlag = 0;
				}
				break;
			case 0x3: // NAND
				A = (~(A & immediate) & 0xF);
				break;
			case 0x4: // CMP
				switch(immediate & 0b0111) {
					case 0: // Set
						conditionalFlag = 1;
						break;
					case 1: // Zero
						conditionalFlag = (A == 0);
						break;
					case 2: // Equal
						conditionalFlag = (A == B);
						break;
					case 3: // Sign
						conditionalFlag = ((A&0b1000) >> 3);
						break;
					default:
						break;
				}
				break;
			case 0x5: // ST
				mem[immediate] = (A << 4) | B;
				break;
			case 0x6: // STPC
				mem[immediate] = ((PC&0x00F) << 4) | B;
				break;
			case 0x7: // JP
				PC = immediate;
				jumped = 1;
				break;
			// B mode
			case 0x8: // LDI
				B = immediate;
				break;
			case 0x9: // LD
				B = mem[immediate] >> 4;
				break;
			case 0xA: // ADD
				A = A + B + conditionalFlag;
				if (A > 0xF) {
					A = A & 0xF;
					conditionalFlag = 1;
				} else {
					conditionalFlag = 0;
				}
				break;
			case 0xB: // NAND
				A = (~(A & B) & 0xF);
				break;
			case 0xC: // CMP
				switch(immediate & 0b0111) {
					case 0: // Reset
						conditionalFlag = 0;
						break;
					case 1: // Not Zero
						conditionalFlag = ~(A == 0);
						break;
					case 2: // Not Equal
						conditionalFlag = ~(A == B);
						break;
					case 3: // Not Sign
						conditionalFlag = ~((A&0b1000) >> 3);
						break;
					default:
						break;
				}
				break;
			case 0xD: // ST
				mem[immediate] = (B << 4) | B;
				break;
			case 0xE: // STPC
				mem[immediate] = ((PC&0xFF0) >> 4);
				break;
			case 0xF: // JPC
				if (conditionalFlag) {
					PC = immediate;
					jumped = 1;
				}
				break;
		}
		if (debugOutput & printExecInst) {
			printExecutedInstruction();
		}
		// Limit Registers to intended Range
		A         = A          &  0x0F;
		B         = B          &  0x0F;
		PC        = PC         & 0xFFF;
		conditionalFlag = conditionalFlag  & 0x01;
		// Print changes
		if (debugOutput & printChanges) {
			if (A != oldA) {
				printIndent();
				printf("A:\t%01X -> %01X\n", oldA, A);
			}
			if (B != oldB) {
				printIndent();
				printf("B:\t%01X -> %01X\n", oldB, B);
			}
			if (PC != oldPC) {
				printIndent();
				printf("PC:\t%02X -> %02X\n", oldPC, PC);
			}
			if (conditionalFlag != oldConditionalFlag) {
				printIndent();
				printf("Cond:\t%d -> %d\n", oldConditionalFlag, conditionalFlag);
			}
		}

		if (!jumped) {
			PC++;
		} else {
			jumped = 0;
		}
		oldA = A;
		oldB = B;
		oldPC = PC;
		oldConditionalFlag = conditionalFlag;
		currentCycle++;
	}
	return 0;
}

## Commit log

2024-02-27 added kicad pcb
    [befour.kicad_pcb, befour.kicad_sch]
2024-02-29 started work on schematic
    [befour.kicad_pcb, befour.kicad_sch]
2024-03-02 more pcb work
    [befour.kicad_pcb, befour.kicad_sch]
2024-03-03 the Schematic is complete.
    [befour.kicad_pcb, befour.kicad_sch]
2024-03-04 schematic tweaks
    [befour.kicad_pcb, befour.kicad_sch]
